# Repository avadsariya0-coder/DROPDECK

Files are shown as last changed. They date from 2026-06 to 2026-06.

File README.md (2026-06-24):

# DROPDECK
A Macropad with dual mode.
___________________________________________________________________________________________________________________________________________________________________________

## Overview

Dropdeck is compact custom built macropad with 5 machanical switches,1 infinite rotary encoder , 1 potentiometer and seed studio XIAO RP2040.128X32 pixels display
Dropdeck has 2 modes chill mode for the normal usage like desktop productivity and the Beast mode for the AAA title gaming.
___________________________________________________________________________________________________________________________________________________________________________

## Inspiration

The inspiration for the Dropdeck came from challenge faced by me during the gaming and normal usage to use shortcuts.
The Dropdeck fixes that problems as in chill mode it will help in using shortcuts easily for opening/closing tab,screenshot and in Beastmode or quick game interactions like healing , loadout etc
It is not built to replace the keyboard its built to make life easier while gaming and productive task.
___________________________________________________________________________________________________________________________________________________________________________

## Features

• dual modes

• analog volume mixer

• quick actions in game

•  Volume increase and decrease
_________________________________________________________________________________________________________________________________________________________________________

## Gallery

DROPDECK

right render

BACK RENDER
_________________________________________________________________________________________________________________________________________________________________________

## Hardware Stack

• 5X MX cherry mechanical switches

• 1X infinite rotary encoder

• 1X Potentiomrter

• 1X 128X32 pixels Display

• 1X Seed stiudio XIAO RP2040
_________________________________________________________________________________________________________________________________________________________________________

## Bill Of Material



[BOM DROPDECK.csv](https://github.com/user-attachments/files/29165464/BOM.DROPDECK.csv)
_________________________________________________________________________________________________________________________________________________________________________

## Zine 

DROPDECK

_________________________________________________________________________________________________________________________________________________________________________

## PCB Design

The PCB used is custom designed using kicad. It includes MX cherry switches,display,potentiometer,rotary encoder,XIAO RP2040

## Features

• Custom Design

• Compact Design

• Mechanical switches

• Potentiometer

• rotary encoder
_________________________________________________________________________________________________________________________________________________________________________

## PCB

PCB
_________________________________________________________________________________________________________________________________________________________________________

## Schematic

SCHEMATIC
_________________________________________________________________________________________________________________________________________________________________________

## Enclosure

The enclosure is designed using Fusion 360.

## Features

• USB-C opening

• Accesible switches,potentiometer,rotary encoder

• Display opening
_________________________________________________________________________________________________________________________________________________________________________

## Assembly Guide

• Solder Xiao RP2040 to the PCB

• Solder switches make sure that it exactly passes through the hole

• Solder Display,potentiometer,Rotary encoder

• Now fix PCB to the bottom enclosure with the help of the M2.5 Screws

• Fix the top case with the help of the Screws
_________________________________________________________________________________________________________________________________________________________________________

## How to use
•  connect it with any USB-C cable

•  The Display shows the mode

• Use switch 5 to change between modes

### chill mode

• switch 1 : Open Tab

• switch 2 : Close Tab

• switch 3 : Screenshot

• switch 4 : Show desktop

• Potentiometer : Analog volume mixer

• Rotary Encoder : Changing volume

### Beast mode

• switch 1 : Heal 

• switch 2 : Tactital ability

• switch 3 : Reload

• switch 4 : Loot/interact

• Potentiometer : Analog volume mixer

• Rotary Encoder : Change inventory
_________________________________________________________________________________________________________________________________________________________________________

## Contributing

Contributions,suggestions, and feedback are welcome

If you'd like to improve DROPDECK
1. Fork or clone the repository
   
(https://github.com/avadsariya0-coder/DROPDECK)

4. Create your Feature branch

5. Commit your changes

6. Open a pull request.

_________________________________________________________________________________________________________________________________________________________________________

## Creator

# Arman Vadsariya

17•India•Fallout

_________________________________________________________________________________________________________________________________________________________________________

## License

This project is licensed under MIT License.

_________________________________________________________________________________________________________________________________________________________________________

# DROPDECK

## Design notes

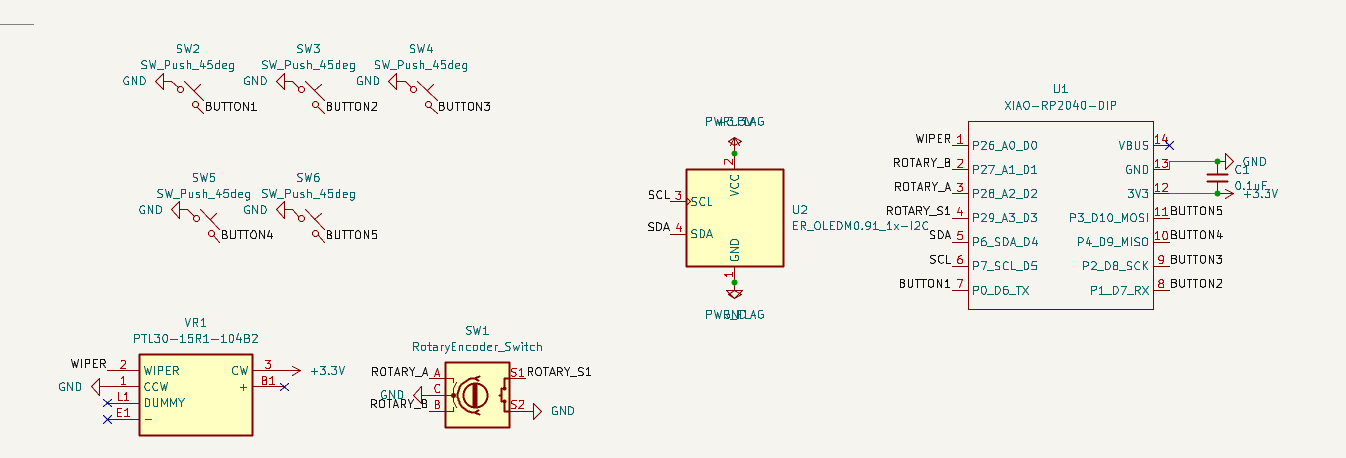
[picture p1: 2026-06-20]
GALLERY/SCHEMATIC.png

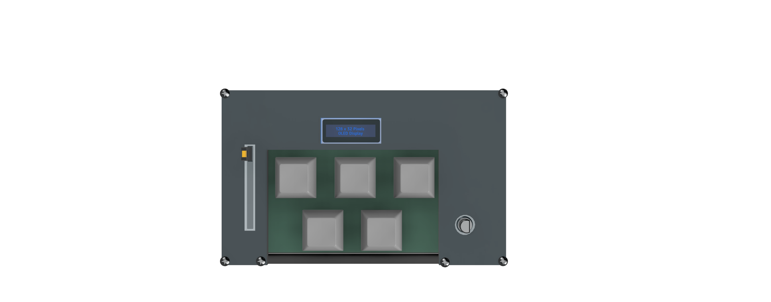
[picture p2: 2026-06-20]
GALLERY/TOP RENDER.png

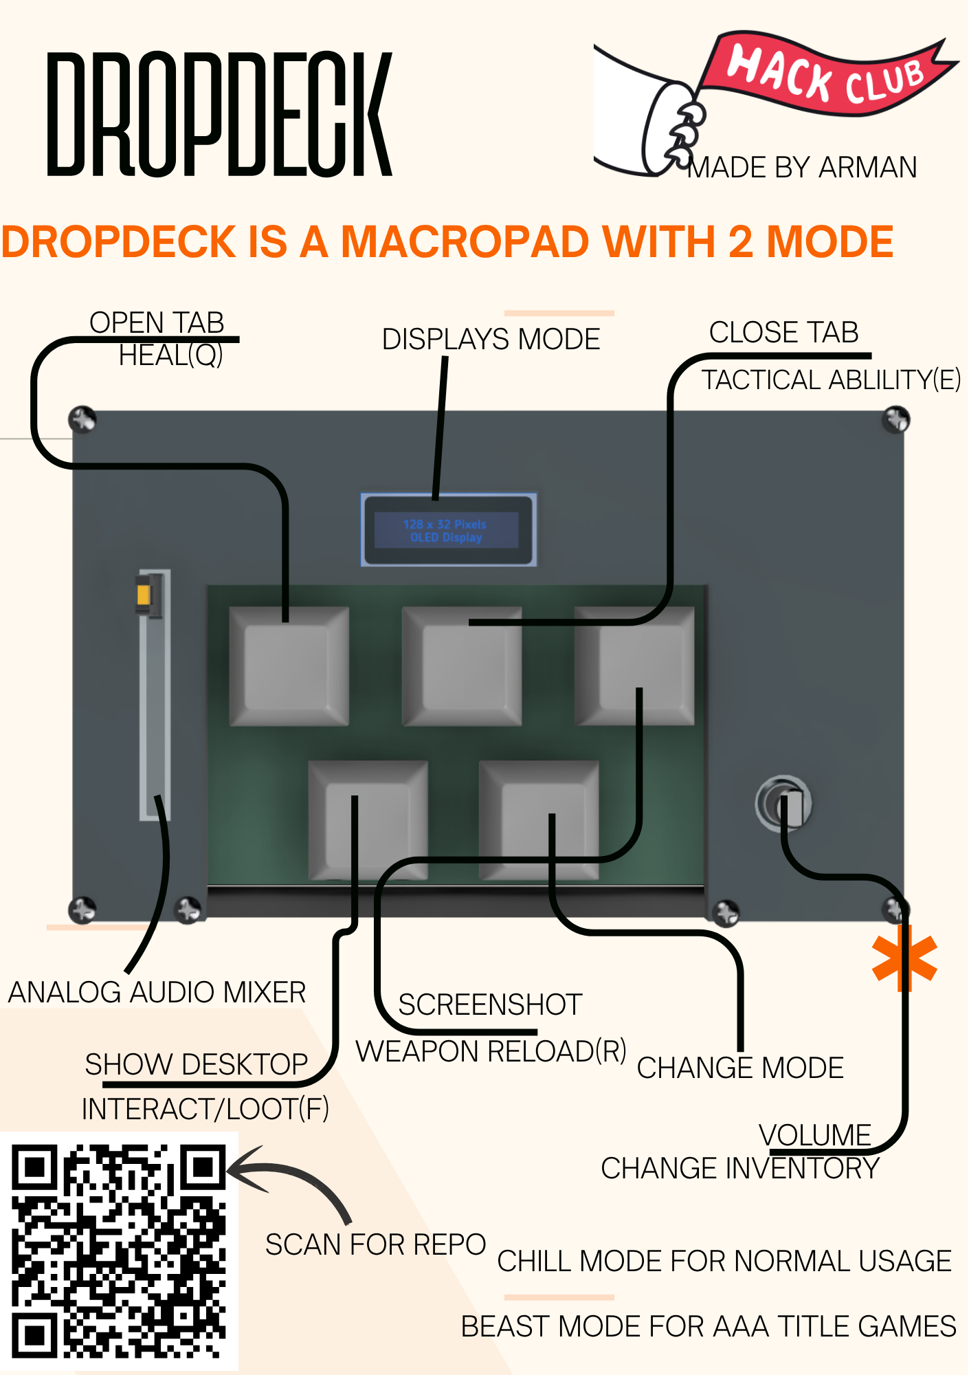
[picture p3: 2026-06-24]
GALLERY/DROPDECK.png

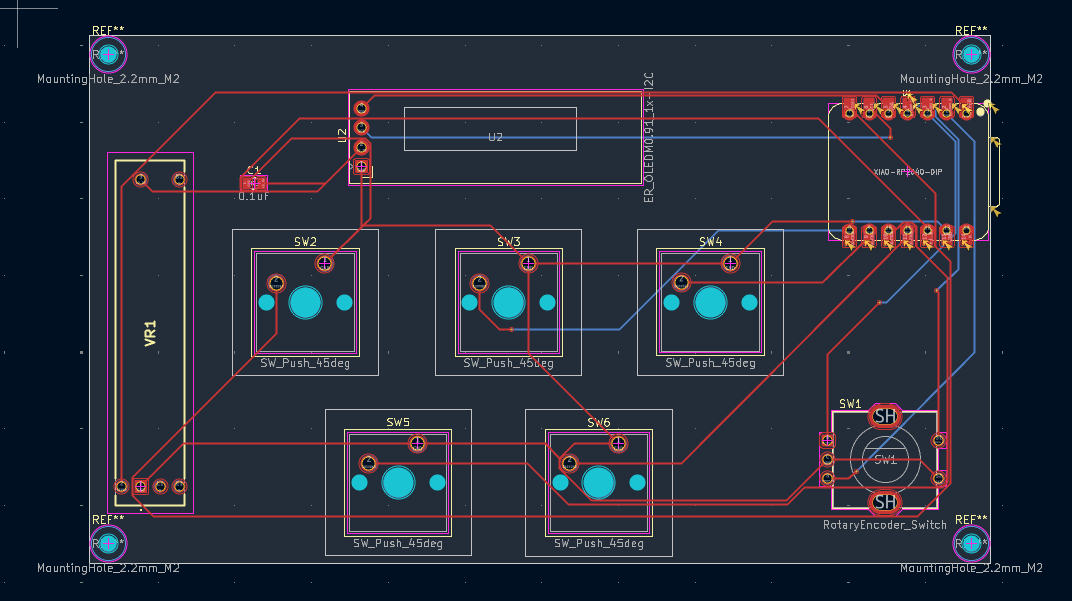
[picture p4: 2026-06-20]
GALLERY/PCB.png

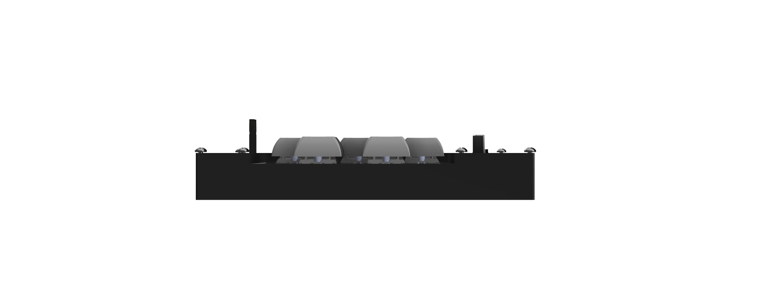
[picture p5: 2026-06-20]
GALLERY/FRONT RENDER.png

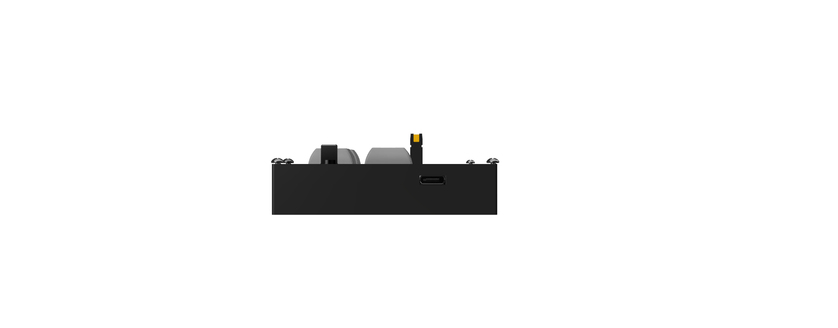
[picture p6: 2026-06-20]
GALLERY/RIGHT RENDER.png

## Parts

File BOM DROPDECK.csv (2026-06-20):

Component | quantity required | Price in inr | Price in USD | Total price | web link
MX cherryswitch | 5 | 37.32 | $0.39 | $3.72 | https://meckeys.com/shop/accessories/keyboard-accessories/key-switches/cherry-mx-rgb-switch/
Xiao RP2040 | 1 | 373.18 | $3.9 | $3.9 | http://seeedstudio.com/XIAO-RP2040-v1-0-p-5026.html
DSA keycaps | 5 | 37.32 | $0.21 | $1.05 | https://meckeys.com/shop/accessories/keyboard-accessories/keycaps/blank/blank-dsa-keycaps-1u/
Potentiometer | 1 | 281.37 | $2.95 | $2.95 | https://www.mouser.com/ProductDetail/Bourns/PTL30-15R1-104B2?qs=b8viKDOLiXZRUw8o0OtIKw%3D%3D
Display | 1 | 263 | $2.76 | $2.76 | https://www.amazon.in/Electrobot-SSD1306-Display-Module-Screen/dp/B099X21CM5
Rotary encoder | 1 | 179.77 | $1.88 | $1.88 | https://www.arrow.com/en/products/pec11r-4215k-s0024/bourns.html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
PCB | 1 | 707.48 | $7.5 | $7.5 | https://cart.jlcpcb.com/quote?rand=0.8516392589623124
enclosure | 1 | 326.22 | $3.42 | $3.42 | https://jlc3dp.com/3d-printing-quote
M2.5 screws | 6 | 4 | $0.042 | $0.252 | https://in.misumi-ec.com/vona2/detail/221000547337/?HissuCode=CSPTRT-SUS-M2.5-5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
M2.2 screws | 4 | 5 | $0.053 | $0.212 | https://www.indiamart.com/proddetail/torx-screw-m2-2-x-5-2850107426012.html
 |  |  | Grand Total | $27.644

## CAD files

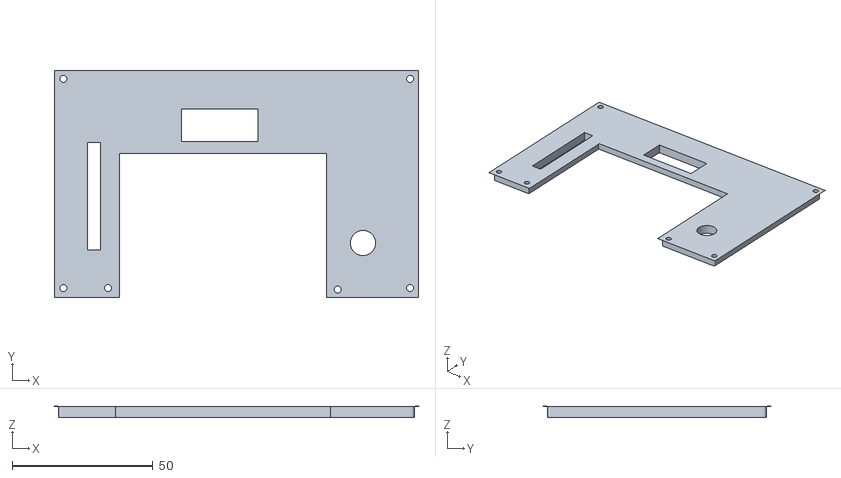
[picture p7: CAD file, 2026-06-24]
C.A.D/Body4.stl
129.5 x 80.8 x 4.00

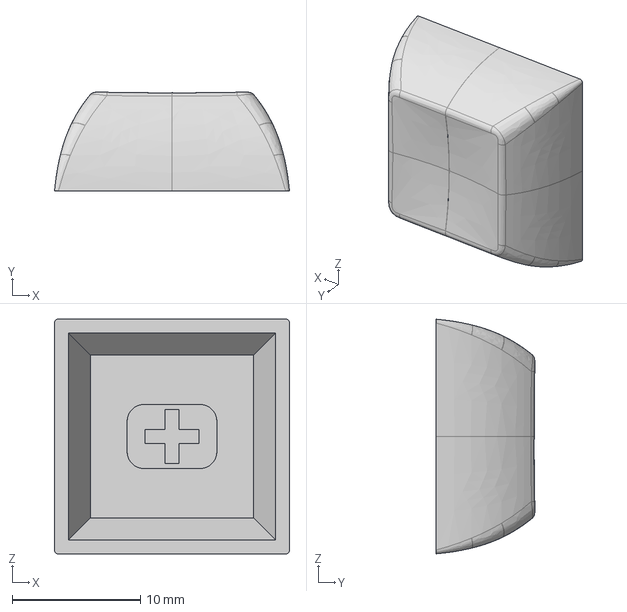
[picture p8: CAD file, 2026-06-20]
C.A.D/STEP/DSA_Keycap_CherryMX.step
18.3 x 7.69 x 18.3 mm

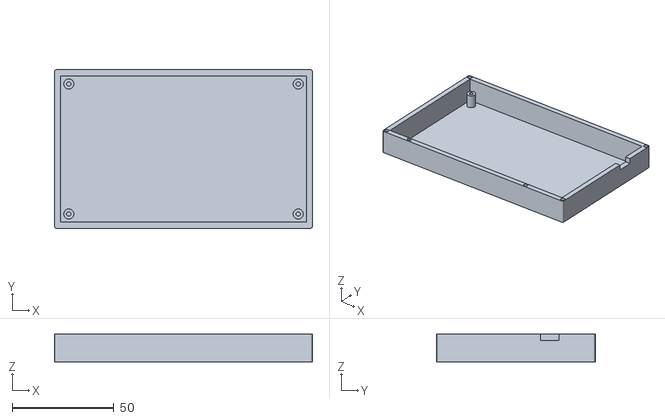
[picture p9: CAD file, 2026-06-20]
C.A.D/Body1.stl
126.5 x 77.8 x 13.5

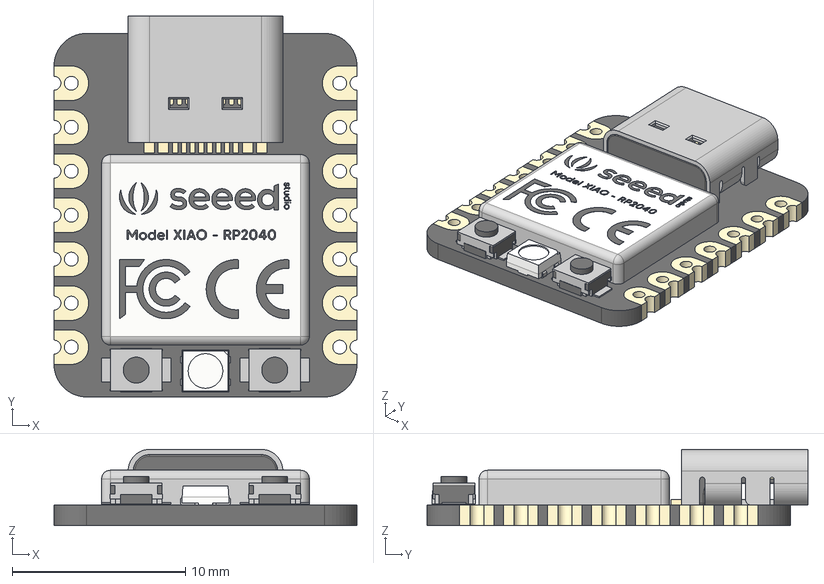
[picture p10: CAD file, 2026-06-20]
C.A.D/STEP/Seeed Studio XIAO RP2040 v26.step
17.5 x 22.0 x 4.40 mm
type-c v2
smd_button v3
DOUT
DIN
VSS
VDD
smd_button v3(Mirror)

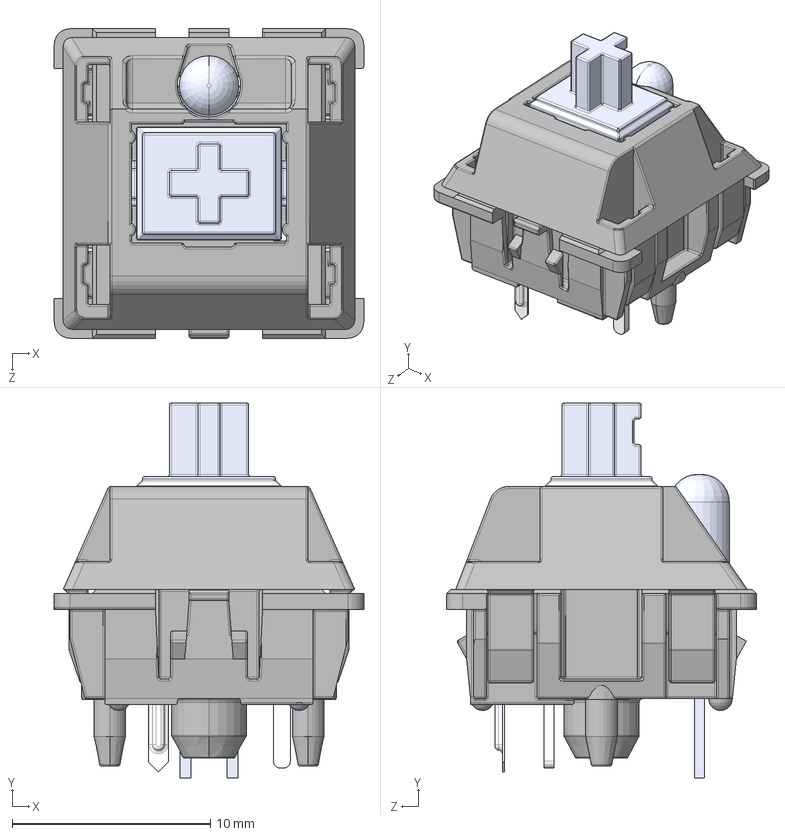
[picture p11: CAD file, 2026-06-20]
C.A.D/STEP/MX .STEP
15.6 x 18.9 x 15.6 mm
MX 轴 按键′_ü___¨1
MX 轴 轴体áì_¨￠¨__
MX粣 拸簽LEDLEDLED
MX轴 轴体 底部 μ×2__默认_á2____è_
针脚___默认__è_

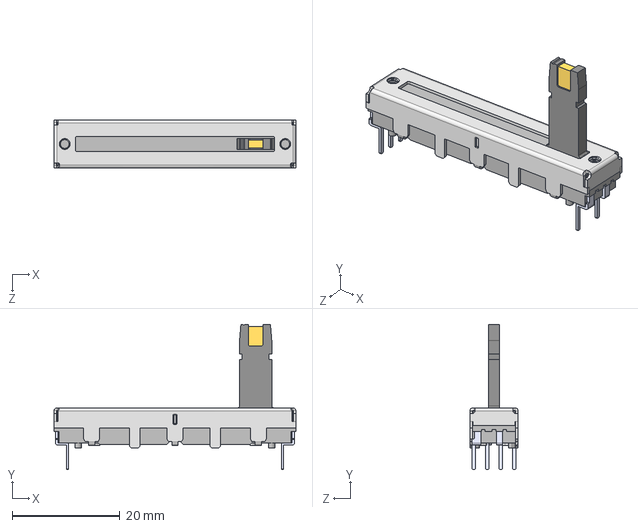
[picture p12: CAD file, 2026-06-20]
C.A.D/STEP/PTL30-15R1-104B2.STEP
45.0 x 27.0 x 9.00 mm

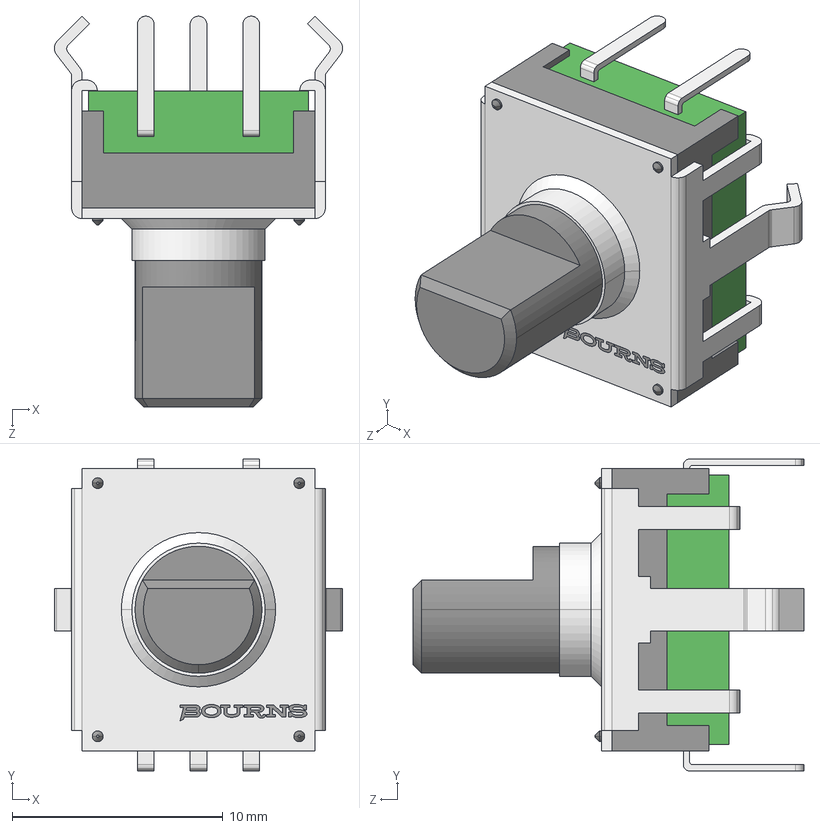
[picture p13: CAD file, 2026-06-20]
C.A.D/STEP/PEC12R-4015F-S0024.stp
13.7 x 14.8 x 18.5 mm
Bourns.STEP

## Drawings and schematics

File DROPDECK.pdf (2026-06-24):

# DROPDECK

## DROPDECK IS A MACROPAD WITH 2 MODE

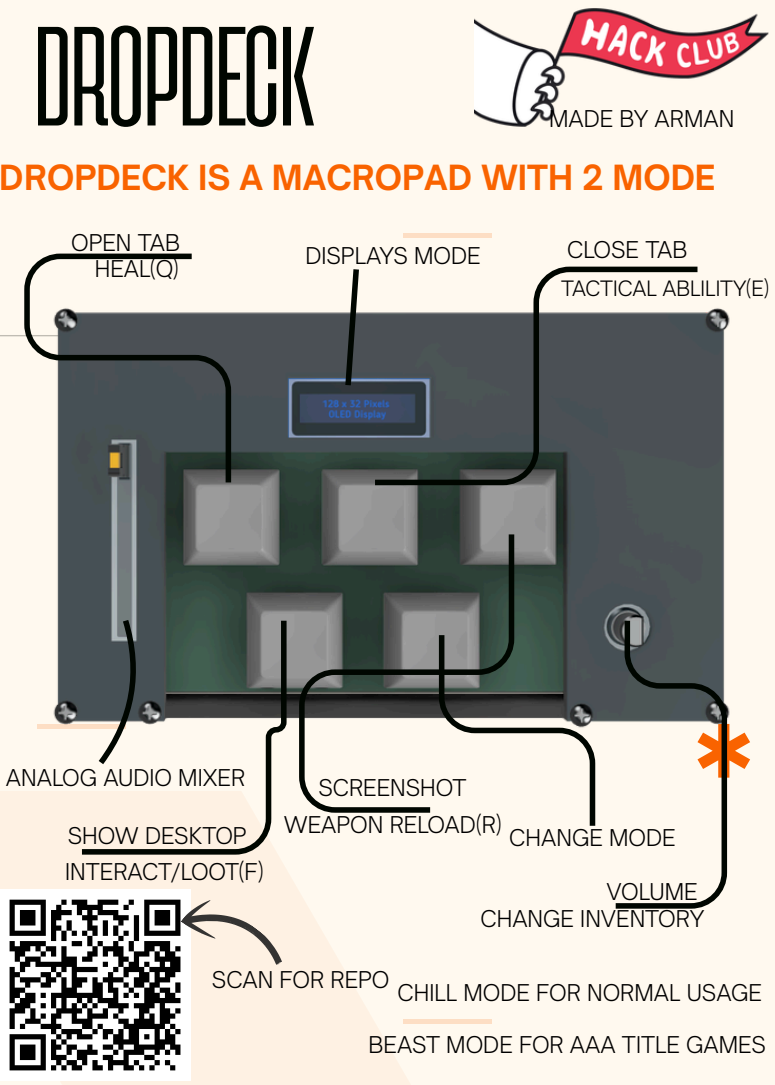
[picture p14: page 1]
CHANGE MODE; DISPLAYS MODE; WEAPON RELOAD(R); VOLUME CHANGE INVENTORY; OPEN TAB HEAL(Q); CLOSE TAB; TACTICAL ABLILITY(E); SCREENSHOT; SHOW DESKTOP INTERACT/LOOT(F)

MADE BY ARMAN

ANALOG AUDIO MIXER

SCAN FOR REPO

CHILL MODE FOR NORMAL USAGE
BEAST MODE FOR AAA TITLE GAMES

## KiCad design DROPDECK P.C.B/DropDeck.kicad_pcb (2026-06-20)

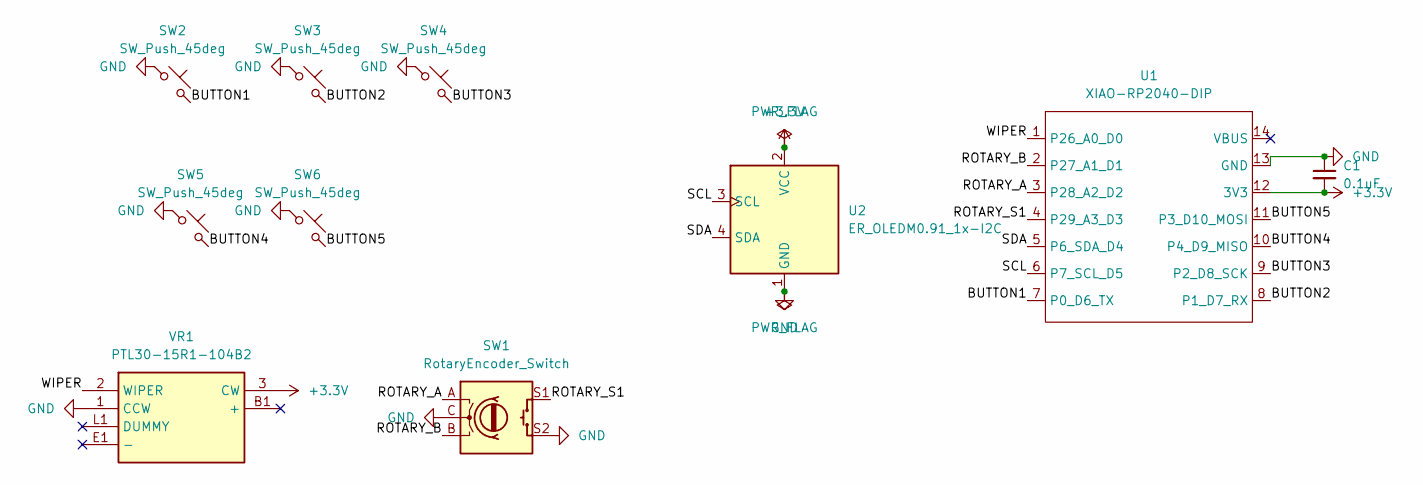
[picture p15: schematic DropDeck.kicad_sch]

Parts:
C1: 0.1uF; C_0805_2012Metric
SW1: RotaryEncoder_Switch; RotaryEncoder_Bourns_Vertical_PEC12R-3x17F-Sxxxx
SW2, SW3, SW4, SW5, SW6: SW_Push_45deg; SW_Cherry_MX_1.00u_PCB
U1: XIAO-RP2040-DIP
U2: ER_OLEDM0.91_1x-I2C
VR1: PTL30-15R1-104B2; PTL3015R1104B2; Manufacturer_Part_Number PTL30-15R1-104B2

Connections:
+3.3V: C1.2, U1.12 (3V3), U2.2 (VCC), VR1.3 (CW)
/BUTTON1: SW2.2, U1.7 (P0_D6_TX)
/BUTTON2: SW3.2, U1.8 (P1_D7_RX)
/BUTTON3: SW4.2, U1.9 (P2_D8_SCK)
/BUTTON4: SW5.2, U1.10 (P4_D9_MISO)
/BUTTON5: SW6.2, U1.11 (P3_D10_MOSI)
/ROTARY_A: SW1.A, U1.3 (P28_A2_D2)
/ROTARY_B: SW1.B, U1.2 (P27_A1_D1)
/ROTARY_S1: SW1.S1, U1.4 (P29_A3_D3)
/SCL: U1.6 (P7_SCL_D5), U2.3 (SCL)
/SDA: U1.5 (P6_SDA_D4), U2.4 (SDA)
/WIPER: U1.1 (P26_A0_D0), VR1.2 (WIPER)
GND: C1.1, SW1.C, SW1.S2, SW2.1, SW3.1, SW4.1, SW5.1, SW6.1, U1.13 (GND), U2.1 (GND), VR1.1 (CCW)

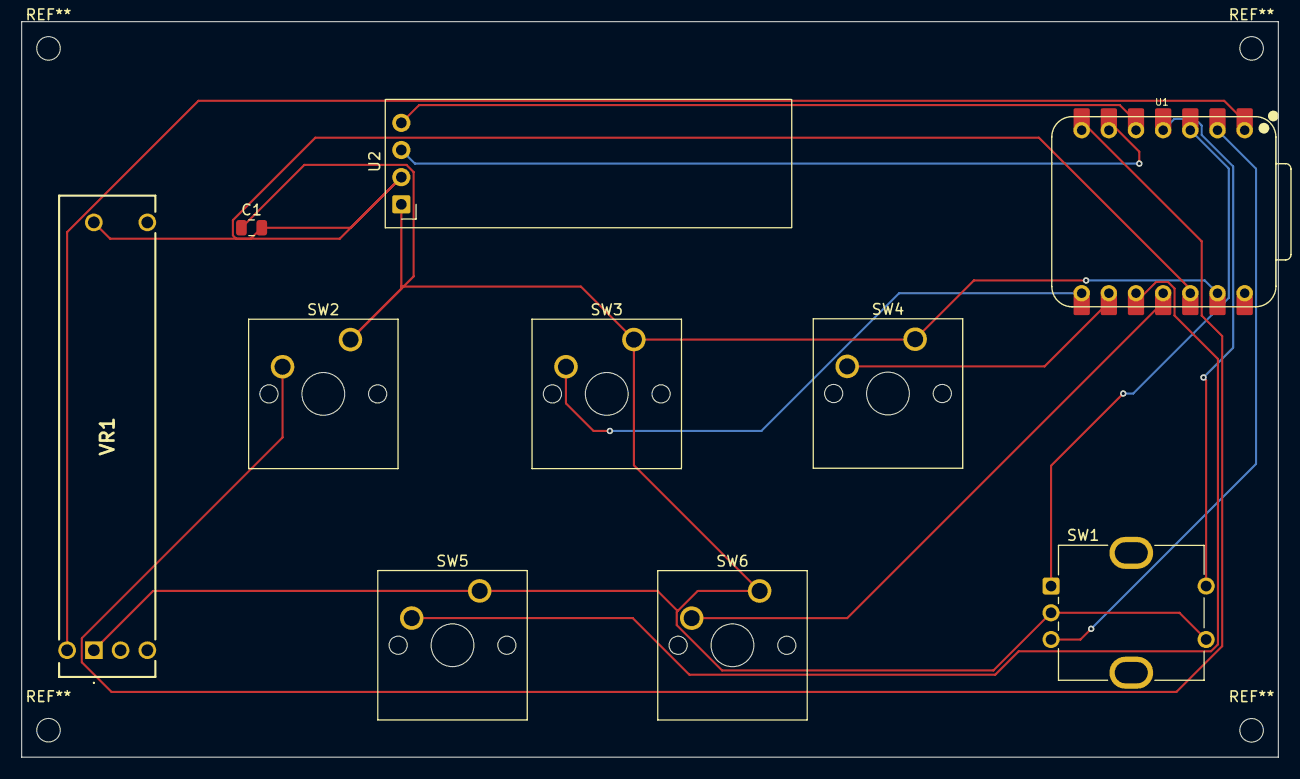
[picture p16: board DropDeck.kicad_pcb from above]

Board: 2 copper layers, 117.5 x 68.8 mm, 10 parts (0 on the bottom side), 13 nets.

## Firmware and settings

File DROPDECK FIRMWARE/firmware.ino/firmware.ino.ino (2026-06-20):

#include <Adafruit_TinyUSB.h>
#include <Wire.h>
#include <Adafruit_GFX.h>
#include <Adafruit_SSD1306.h>
#include <RotaryEncoder.h>

#define SCREEN_WIDTH 128
#define SCREEN_HEIGHT 32
#define OLED_RESET -1
#define SCREEN_ADDRESS 0x3C

Adafruit_SSD1306 display(SCREEN_WIDTH, SCREEN_HEIGHT, &Wire, OLED_RESET);
RotaryEncoder encoder(D2, D1, RotaryEncoder::LatchMode::FOUR3);

const int sliderPin = A0; 
const int switchPins[5] = {D6, D7, D8, D9, D10};

int currentLayer = 0;
bool lastSwitch5State = HIGH;
int lastEncoderPos = 0;
int currentVolumeLevel = 15; 

uint8_t const desc_hid_report[] = {
  TUD_HID_REPORT_DESC_KEYBOARD(HID_REPORT_ID(1)),
  TUD_HID_REPORT_DESC_MOUSE(HID_REPORT_ID(2)),
  TUD_HID_REPORT_DESC_CONSUMER(HID_REPORT_ID(3))
};

Adafruit_USBD_HID usb_hid(desc_hid_report, sizeof(desc_hid_report), HID_ITF_PROTOCOL_NONE, 2, false);

void sendConsumerKey(uint16_t usage_code) {
  usb_hid.sendReport(3, &usage_code, 2);
  uint16_t release = 0;
  usb_hid.sendReport(3, &release, 2);
  delay(10); 
}

void updateDisplay() {
  display.clearDisplay();
  display.setTextColor(SSD1306_WHITE);
  
  display.setTextSize(2);
  display.setCursor(0, 0);
  if (currentLayer == 0) {
    display.print("CHILL");
  } else {
    display.print("BEAST");
  }
  
  display.setTextSize(1);
  display.setCursor(0, 20);
  if (currentLayer == 0) {
    display.print("DESKTOP MODE");
  } else {
    display.print("TACTICAL LOADOUT");
  }
  
  display.display();
}

void setup() {
  usb_hid.begin();
  
  Wire.setSDA(D4);
  Wire.setSCL(D5);
  Wire.begin();
  
  if(!display.begin(SSD1306_SWITCHCAPVCC, SCREEN_ADDRESS)) {
    for(;;);
  }
  
  updateDisplay();
  
  for (int i = 0; i < 5; i++) {
    pinMode(switchPins[i], INPUT_PULLUP);
  }
  
  while( !TinyUSBDevice.mounted() ) delay(1);
}

void loop() {
  if ( !usb_hid.ready() ) return;

  encoder.tick();
  int currentEncoderPos = encoder.getPosition();
  if (currentEncoderPos != lastEncoderPos) {
    if (currentLayer == 1) {
      if (currentEncoderPos > lastEncoderPos) {
        int8_t scroll_step = 1;
        usb_hid.mouseReport(2, 0, 0, 0, scroll_step, 0);
      } else {
        int8_t scroll_step = -1;
        usb_hid.mouseReport(2, 0, 0, 0, scroll_step, 0);
      }
    } else {
      if (currentEncoderPos > lastEncoderPos) {
        sendConsumerKey(HID_USAGE_CONSUMER_VOLUME_INCREMENT);
        if(currentVolumeLevel < 25) currentVolumeLevel++;
      } else {
        sendConsumerKey(HID_USAGE_CONSUMER_VOLUME_DECREMENT);
        if(currentVolumeLevel > 0) currentVolumeLevel--;
      }
    }
    lastEncoderPos = currentEncoderPos;
  }

  int rawSlider = analogRead(sliderPin);
  int targetVolumeLevel = map(rawSlider, 0, 1023, 0, 25); 

  if (abs(targetVolumeLevel - currentVolumeLevel) >= 1) {
    while (currentVolumeLevel < targetVolumeLevel) {
      sendConsumerKey(HID_USAGE_CONSUMER_VOLUME_INCREMENT);
      currentVolumeLevel++;
    }
    while (currentVolumeLevel > targetVolumeLevel) {
      sendConsumerKey(HID_USAGE_CONSUMER_VOLUME_DECREMENT);
      currentVolumeLevel--;
    }
  }

  bool switch5State = digitalRead(switchPins[4]);
  if (switch5State == LOW && lastSwitch5State == HIGH) {
    currentLayer = 1 - currentLayer;
    updateDisplay();
    delay(250);
  }
  lastSwitch5State = switch5State;

  uint8_t keycode[6] = { 0 };

  if (currentLayer == 0) {
    if (digitalRead(switchPins[0]) == LOW) {
      keycode[0] = HID_KEY_T;
      usb_hid.keyboardReport(1, KEYBOARD_MODIFIER_LEFTCTRL, keycode);
      delay(10);
      usb_hid.keyboardRelease(1);
      while(digitalRead(switchPins[0]) == LOW);
    }
    if (digitalRead(switchPins[1]) == LOW) {
      keycode[0] = HID_KEY_W;
      usb_hid.keyboardReport(1, KEYBOARD_MODIFIER_LEFTCTRL, keycode);
      delay(10);
      usb_hid.keyboardRelease(1);
      while(digitalRead(switchPins[1]) == LOW);
    }
    if (digitalRead(switchPins[2]) == LOW) {
      keycode[0] = HID_KEY_S;
      usb_hid.keyboardReport(1, (KEYBOARD_MODIFIER_LEFTCTRL | KEYBOARD_MODIFIER_LEFTSHIFT), keycode);
      delay(10);
      usb_hid.keyboardRelease(1);
      while(digitalRead(switchPins[2]) == LOW);
    }
    if (digitalRead(switchPins[3]) == LOW) {
      keycode[0] = HID_KEY_D;
      usb_hid.keyboardReport(1, KEYBOARD_MODIFIER_LEFTGUI, keycode);
      delay(10);
      usb_hid.keyboardRelease(1);
      while(digitalRead(switchPins[3]) == LOW);
    }
  } 
  else if (currentLayer == 1) {
    if (digitalRead(switchPins[0]) == LOW) {
      keycode[0] = HID_KEY_Q;
      usb_hid.keyboardReport(1, 0, keycode);
      delay(10);
      usb_hid.keyboardRelease(1);
      while(digitalRead(switchPins[0]) == LOW);
    }
    if (digitalRead(switchPins[1]) == LOW) {
      keycode[0] = HID_KEY_E;
      usb_hid.keyboardReport(1, 0, keycode);
      delay(10);
      usb_hid.keyboardRelease(1);
      while(digitalRead(switchPins[1]) == LOW);
    }
    if (digitalRead(switchPins[2]) == LOW) {
      keycode[0] = HID_KEY_R;
      usb_hid.keyboardReport(1, 0, keycode);
      delay(10);
      usb_hid.keyboardRelease(1);
      while(digitalRead(switchPins[2]) == LOW);
    }
    if (digitalRead(switchPins[3]) == LOW) {
      keycode[0] = HID_KEY_F;
      usb_hid.keyboardReport(1, 0, keycode);
      delay(10);
      usb_hid.keyboardRelease(1);
      while(digitalRead(switchPins[3]) == LOW);
    }
  }

  delay(1);
}
